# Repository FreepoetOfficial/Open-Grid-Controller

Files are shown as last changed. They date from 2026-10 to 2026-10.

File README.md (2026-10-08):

# Open Grid Controller

Open Grid Controller is an open-source 8x16 grid controller for music production, live performance, sound experiments, and interactive installations. It uses an RP2040-Zero as the main controller, appears over USB as a monome grid-compatible device, and bridges 128 key inputs plus per-key LED brightness control to two 8x8 I2C keypad/LED boards.

The project includes ready-to-build PlatformIO firmware, STEP files for the 3D-printed enclosure, and reference photos for assembly. You can use it as a complete DIY controller, or adapt it into your own sequencer, visual controller, media installation input panel, or monome-compatible hardware project.

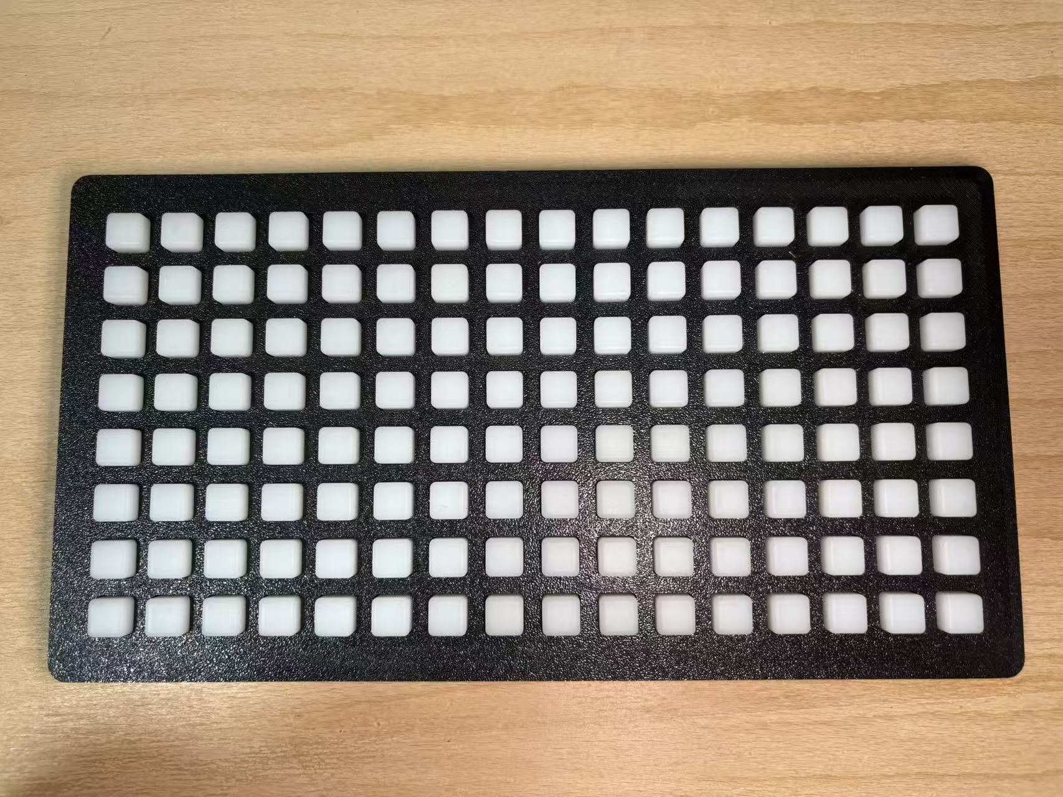
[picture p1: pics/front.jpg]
Open Grid front view


## Features

- 8x16 matrix layout with 128 independently readable keys.
- Per-key LED brightness control with 16 levels, from 0 to 15.
- USB serial protocol compatible with the core monome grid input and LED control workflow.
- Based on RP2040-Zero, Arduino Core, and Adafruit TinyUSB.
- Two 8x8 [FREEPOET-Keypad](https://github.com/FREEPOET-OFFICIAL/FREEPOET_Keypad) I2C boards combine into a full 16-column grid.
- Supports key debouncing, hot-plug detection, full LED sync, and incremental LED refresh.
- Includes 3D-printable enclosure files for replication and customization.

## Product Photos

The front panel uses a classic 16-column, 8-row grid layout, suitable for step sequencing, clip launching, parameter mapping, and mode switching.

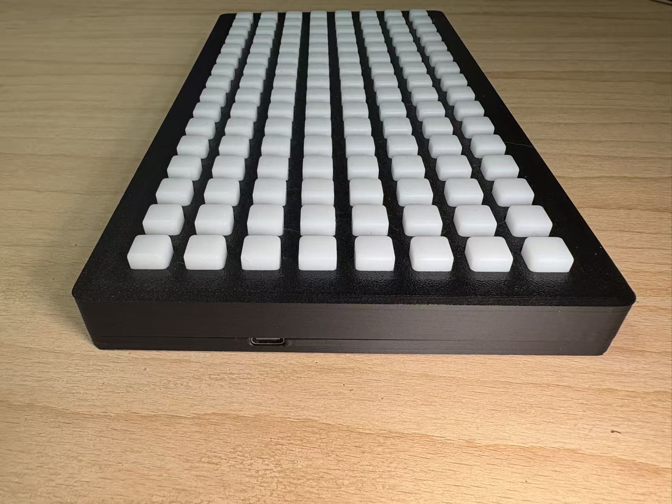
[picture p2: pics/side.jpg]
Open Grid side view


The enclosure has a low-profile desktop form factor with a side USB port, making it comfortable to keep beside a synthesizer, controller, or computer.

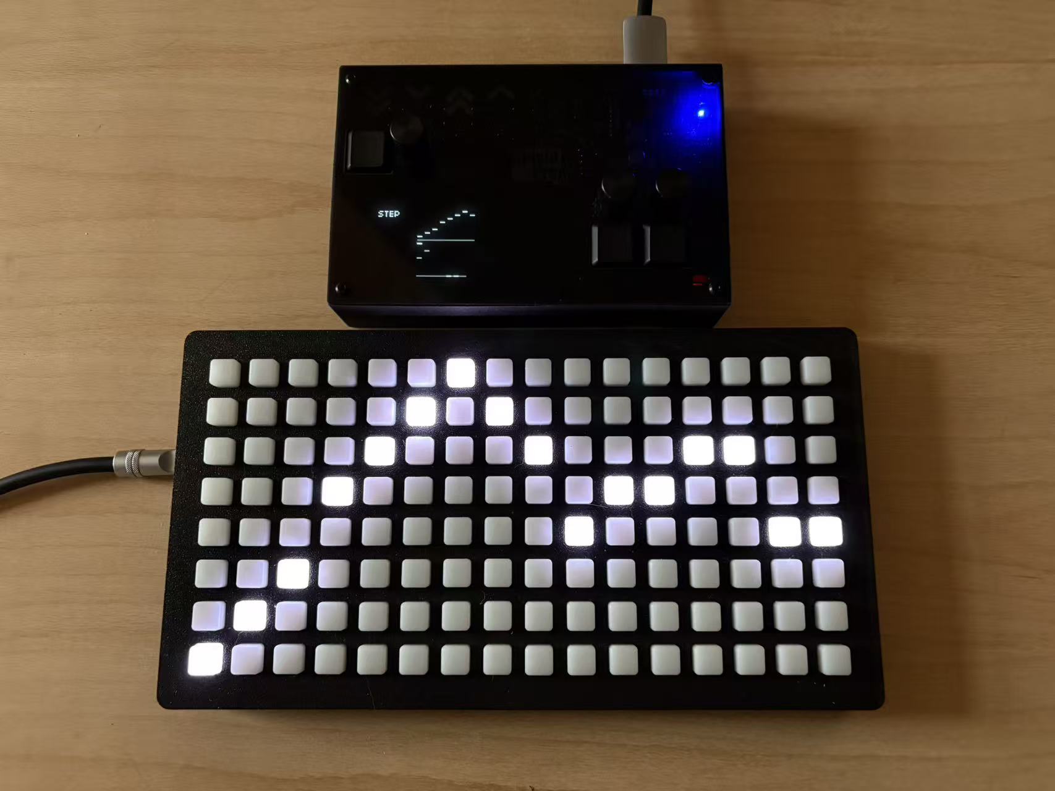
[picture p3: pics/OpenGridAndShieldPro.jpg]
Open Grid with Shield Pro


Open Grid can be used alongside other hardware controllers. The photo above shows it working with Shield Pro on the same desktop, forming a more complete live performance control setup.

## Hardware

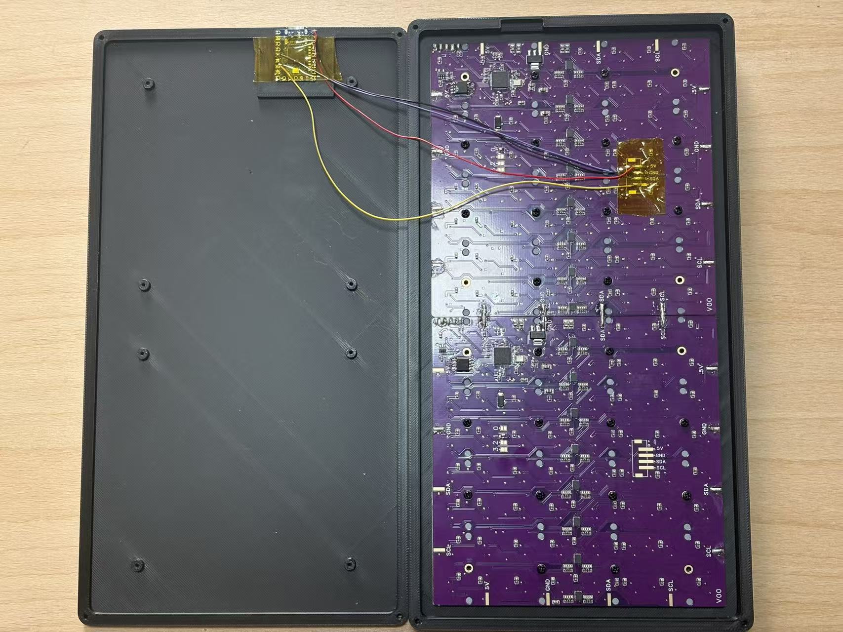
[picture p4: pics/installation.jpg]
Open Grid internal assembly


## Bill of Materials

FREEPOET OpenGrid kit: https://github.com/FREEPOET-OFFICIAL/FREEPOET_Keypad

- RP2040-Zero main controller board.
- Two 8x8 FREEPOET_Keypad key/LED boards.
- Eight 4x4 silicone pads.

Parts to prepare separately:

- 3D-printed top cover and bottom shell.
- 4 wires.
- 24pcs M2*6 mm self-tapping screws.
- 8pcs M2*10 mm self-tapping screws.
- 6pcs M3*8 mm self-tapping screws.

The firmware uses Pico I2C0 by default:

- SDA: GPIO 4
- SCL: GPIO 5
- I2C speed: 100 kHz

Select the address jumpers as shown by the red circles in the image below:

- Board 1: solder the address bit 0 jumper.
- Board 2: solder the address bit 1 jumper.

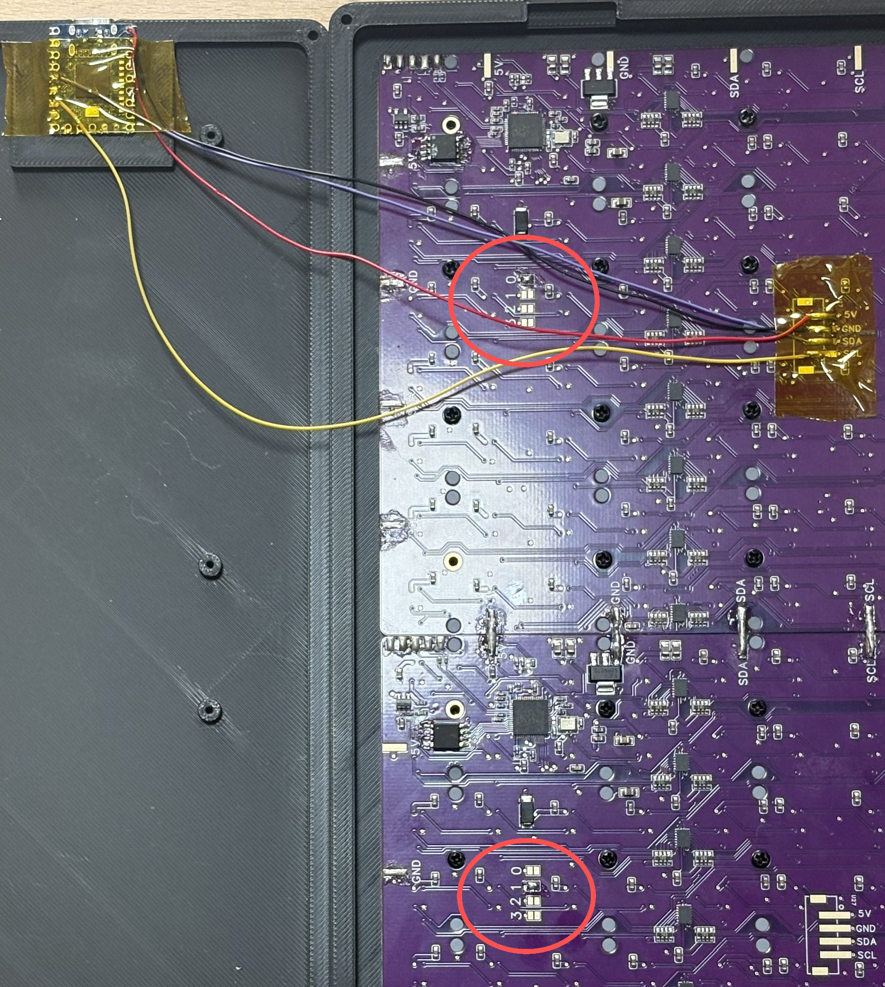
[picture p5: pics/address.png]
Address jumper selection


## Repository Structure

```text
.
├── enclosure/              # 3D enclosure STEP files
│   ├── OpenGrid-Bot.step
│   └── OpenGrid-Top.step
├── pics/                   # README and assembly reference images
└── sw/                     # PlatformIO firmware project
    ├── platformio.ini
    └── src/
```

## Firmware Build and Upload

The firmware is built with PlatformIO. The target board is Raspberry Pi Pico.

1. Install VS Code and the PlatformIO extension.
2. Open the `sw` directory in this repository.
3. Connect the RP2040-Zero.
4. Build and upload the firmware:

```bash
cd sw
pio run -t upload
```

## Software Compatibility

On the USB side, Open Grid uses a monome-style serial device descriptor and reports `OpenGrid` as the device ID. The firmware implements common commands such as grid size query, device ID handling, key event reporting, and single-pixel, region, and full-grid LED control. It is intended to work with music software, scripts, or custom toolchains that support monome grid devices.

The current firmware focuses on providing a stable 8x16 grid interaction layer. If your software depends on more complete monome protocol behavior, test it against your target application and extend `sw/src/MonomeSerialDevice.cpp` as needed.

## Enclosure and Assembly

The enclosure STEP files are in `enclosure/`:

- `OpenGrid-Top.step`: top cover.
- `OpenGrid-Bot.step`: bottom shell.

## Use Cases

- Sequencer and rhythm programming controller.
- Grid input panel for Max/MSP, norns, SuperCollider, Pure Data, and similar creative environments.
- Lighting, visual, and media installation control surface.
- monome protocol learning and open-source hardware experimentation.
- Hardware foundation for custom MIDI, OSC, or USB controllers.

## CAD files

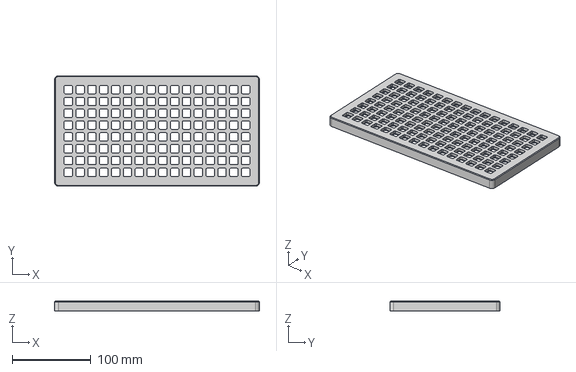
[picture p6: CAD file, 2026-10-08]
enclosure/OpenGrid-Top.step
260.0 x 140.0 x 12.8 mm

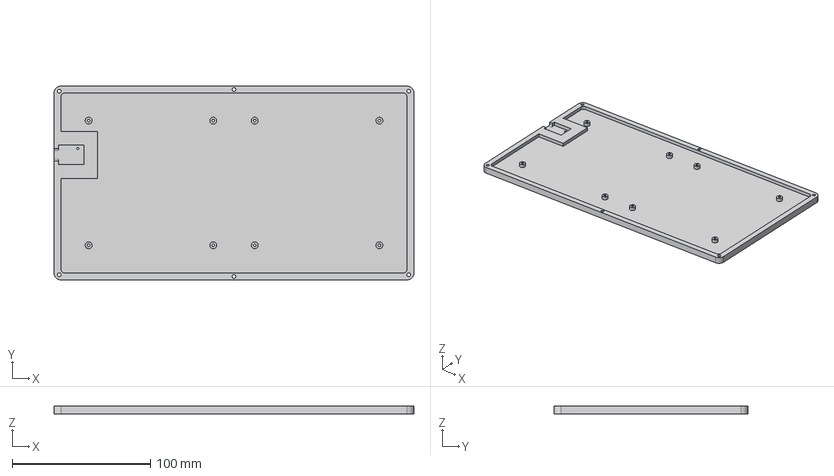
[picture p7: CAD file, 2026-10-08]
enclosure/OpenGrid-Bot.step
260.0 x 140.0 x 5.66 mm

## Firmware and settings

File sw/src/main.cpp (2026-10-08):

#include <Adafruit_TinyUSB.h>

#include "MonomeSerialDevice.h"
#include "keypad.h"

namespace {

constexpr uint32_t kKeyScanIntervalMs = 4;
constexpr uint32_t kLedRefreshIntervalMs = 8;

char manufacturerString[] = "monome";
char productString[] = "monome";
char serialString[] = "m6000000";

MonomeSerialDevice monomeDevice;
Keypad grid;
uint8_t previousLedBuffer[Keypad::kKeyCount] = {0};
uint32_t lastKeyScanMs = 0;
uint32_t lastLedRefreshMs = 0;

void processKeyInput() {
  for (uint8_t keyIndex = 0; keyIndex < grid.getTotalKeys(); ++keyIndex) {
    const uint8_t x = keyIndex / Keypad::kRows;
    const uint8_t y = keyIndex % Keypad::kRows;

    if (grid.wasKeyPressed(keyIndex)) {
      monomeDevice.queueGridKey(x, y, 1);
    } else if (grid.wasKeyReleased(keyIndex)) {
      monomeDevice.queueGridKey(x, y, 0);
    }
  }
}

void sendLeds() {
  bool dirty = false;

  for (uint8_t index = 0; index < Keypad::kKeyCount; ++index) {
    const uint8_t value = monomeDevice.leds[index];
    if (value == previousLedBuffer[index]) {
      continue;
    }

    const uint8_t x = index % Keypad::kCols;
    const uint8_t y = index / Keypad::kCols;
    const uint8_t hardwareIndex = y + x * Keypad::kRows;
    grid.setPixelColor(hardwareIndex, value);
    previousLedBuffer[index] = value;
    dirty = true;
  }

  if (dirty || grid.needsLedSync()) {
    grid.update();
  }
}

}  // namespace

void setup() {
  TinyUSBDevice.setManufacturerDescriptor(manufacturerString);
  TinyUSBDevice.setProductDescriptor(productString);
  TinyUSBDevice.setSerialDescriptor(serialString);

  Serial.begin(115200);

  const uint32_t mountDeadline = millis() + 3000;
  while (!TinyUSBDevice.mounted() && millis() < mountDeadline) {
    delay(1);
  }

  monomeDevice.deviceID = "OpenGrid";
  monomeDevice.isMonome = true;
  monomeDevice.setupAsGrid(Keypad::kRows, Keypad::kCols);

  grid.begin();

  for (uint8_t index = 0; index < 8; ++index) {
    monomeDevice.poll();
    delay(20);
  }

  Serial.println("[USB] monome grid bridge ready");
}

void loop() {
  monomeDevice.poll();

  const uint32_t now = millis();
  if (now - lastKeyScanMs >= kKeyScanIntervalMs) {
    grid.scanKeypad();
    processKeyInput();
    lastKeyScanMs = now;
  }

  if (now - lastLedRefreshMs >= kLedRefreshIntervalMs) {
    sendLeds();
    lastLedRefreshMs = now;
  }

  monomeDevice.poll();

  monomeDevice.flushGridKeyQueue();
}

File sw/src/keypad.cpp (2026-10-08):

#include "keypad.h"

#include <Wire.h>

const Keypad::BoardConfig Keypad::kBoardConfigs[Keypad::kBoardCount] = {
    {0x2E, 0},
    {0x2D, 8},
};

bool Keypad::begin() {
    Wire.setSDA(kI2cSdaPin);
    Wire.setSCL(kI2cSclPin);
    Wire.begin();
    Wire.setClock(kI2cSpeedHz);

    for (uint8_t index = 0; index < kKeyCount; ++index) {
        lastSentLevels_[index] = 0xFF;
    }

    for (uint8_t boardIndex = 0; boardIndex < kBoardCount; ++boardIndex) {
        fullLedSync_[boardIndex] = true;
    }

    refreshConnection(true);
    return true;
}

void Keypad::scanKeypad() {
    refreshConnection(false);

    for (uint8_t keyIndex = 0; keyIndex < kKeyCount; ++keyIndex) {
        keyPressedEdge_[keyIndex] = false;
        keyReleasedEdge_[keyIndex] = false;
    }

    const uint32_t now = millis();
    uint8_t block[kReadBlockMax] = {0};

    for (uint8_t boardIndex = 0; boardIndex < kBoardCount; ++boardIndex) {
        if (!boardConnected_[boardIndex]) {
            continue;
        }

        const BoardConfig &board = kBoardConfigs[boardIndex];
        bool boardReadFailed = false;
        bool rawStates[kKeysPerBoard] = {false};

        for (uint8_t startKey = 0; startKey < kKeysPerBoard; startKey += kReadBlockMax) {
            if (!readKeyBlock(board.address, startKey, kReadBlockMax, block)) {
                boardReadFailed = true;
                fullLedSync_[boardIndex] = true;
                break;
            }

            for (uint8_t offset = 0; offset < kReadBlockMax; ++offset) {
                rawStates[startKey + offset] = (block[offset] != 0);
            }
        }

        if (boardReadFailed || !boardConnected_[boardIndex]) {
            continue;
        }

        const bool inWarmup = (warmupFrames_[boardIndex] > 0) || (now < warmupUntilMs_[boardIndex]);
        if (warmupFrames_[boardIndex] > 0) {
            --warmupFrames_[boardIndex];
        }
        if (inWarmup) {
            continue;
        }

        for (uint8_t localKey = 0; localKey < kKeysPerBoard; ++localKey) {
            const uint8_t globalKey = localToGlobalKey(boardIndex, localKey);
            const bool rawPressed = rawStates[localKey];

            if (rawPressed == stablePressed_[globalKey]) {
                candidateCount_[globalKey] = 0;
                continue;
            }

            if (rawPressed == candidatePressed_[globalKey]) {
                if (candidateCount_[globalKey] < 0xFF) {
                    ++candidateCount_[globalKey];
                }
            } else {
                candidatePressed_[globalKey] = rawPressed;
                candidateCount_[globalKey] = 1;
            }

            if (candidateCount_[globalKey] >= kDebounceSamples) {
                stablePressed_[globalKey] = rawPressed;
                candidateCount_[globalKey] = 0;
                keyPressedEdge_[globalKey] = rawPressed;
                keyReleasedEdge_[globalKey] = !rawPressed;
            }
        }
    }
}

bool Keypad::wasKeyPressed(uint8_t keyIndex) const {
    return keyIndex < kKeyCount && keyPressedEdge_[keyIndex];
}

bool Keypad::wasKeyReleased(uint8_t keyIndex) const {
    return keyIndex < kKeyCount && keyReleasedEdge_[keyIndex];
}

uint8_t Keypad::getTotalKeys() const {
    return kKeyCount;
}

void Keypad::setPixelColor(uint8_t keyIndex, uint8_t level) {
    if (keyIndex >= kKeyCount) {
        return;
    }

    ledLevels_[keyIndex] = (level > 15) ? 15 : level;
}

void Keypad::clearPixels() {
    for (uint8_t keyIndex = 0; keyIndex < kKeyCount; ++keyIndex) {
        ledLevels_[keyIndex] = 0;
    }
    for (uint8_t boardIndex = 0; boardIndex < kBoardCount; ++boardIndex) {
        fullLedSync_[boardIndex] = true;
    }
}

void Keypad::update() {
    for (uint8_t boardIndex = 0; boardIndex < kBoardCount; ++boardIndex) {
        if (!boardConnected_[boardIndex]) {
            continue;
        }

        const BoardConfig &board = kBoardConfigs[boardIndex];
        bool needsSync = fullLedSync_[boardIndex];

        if (!needsSync) {
            for (uint8_t localKey = 0; localKey < kKeysPerBoard; ++localKey) {
                const uint8_t globalKey = localToGlobalKey(boardIndex, localKey);
                if (ledLevels_[globalKey] != lastSentLevels_[globalKey]) {
                    needsSync = true;
                    break;
                }
            }
        }

        if (!needsSync) {
            continue;
        }

        uint8_t levels[kPackedLevelBlockMax] = {0};
        bool transferFailed = false;

        for (uint8_t startKey = 0; startKey < kKeysPerBoard; startKey += kPackedLevelBlockMax) {
            const uint8_t count = static_cast<uint8_t>(min<uint8_t>(kPackedLevelBlockMax, kKeysPerBoard - startKey));
            for (uint8_t offset = 0; offset < count; ++offset) {
                const uint8_t globalKey = localToGlobalKey(boardIndex, static_cast<uint8_t>(startKey + offset));
                levels[offset] = ledLevels_[globalKey] & 0x0F;
            }

            if (!writePackedLevelBlock(board.address, startKey, count, levels)) {
                transferFailed = true;
                break;
            }
        }

        if (transferFailed) {
            fullLedSync_[boardIndex] = true;
            continue;
        }

        if (!showLeds(board.address)) {
            fullLedSync_[boardIndex] = true;
            continue;
        }

        for (uint8_t localKey = 0; localKey < kKeysPerBoard; ++localKey) {
            const uint8_t globalKey = localToGlobalKey(boardIndex, localKey);
            lastSentLevels_[globalKey] = ledLevels_[globalKey];
        }

        fullLedSync_[boardIndex] = false;
    }
}

bool Keypad::isConnected() const {
    for (uint8_t boardIndex = 0; boardIndex < kBoardCount; ++boardIndex) {
        if (boardConnected_[boardIndex]) {
            return true;
        }
    }
    return false;
}

bool Keypad::needsLedSync() const {
    for (uint8_t boardIndex = 0; boardIndex < kBoardCount; ++boardIndex) {
        if (boardConnected_[boardIndex] && fullLedSync_[boardIndex]) {
            return true;
        }
    }
    return false;
}
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
